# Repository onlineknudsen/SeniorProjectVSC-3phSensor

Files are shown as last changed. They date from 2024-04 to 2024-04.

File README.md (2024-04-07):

View this project on [CADLAB.io](https://cadlab.io/project/28017).

# Senior Project - Voltage Sourced Converter - 3 phase Power Sensor
### Lin Knudsen, Thomas Mack, Nikhil Patel
Chip: Atmel M90E32AS Enhanced Poly-Phase High-Performance Wide-Span
Energy Metering IC

[Datasheet](https://ww1.microchip.com/downloads/aemDocuments/documents/OTH/ProductDocuments/DataSheets/Atmel-46003-SE-M90E32AS-Datasheet.pdf)

[Application Notes](https://ww1.microchip.com/downloads/aemDocuments/documents/OTH/ApplicationNotes/ApplicationNotes/Atmel-46103-SE-M90E32AS-ApplicationNote.pdf)

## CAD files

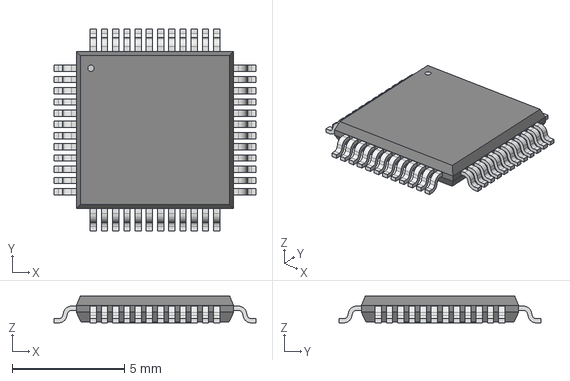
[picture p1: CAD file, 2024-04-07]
ATM90E32AS_AU_R/TQFP48_7x7MC_MCH.step
8.99 x 8.99 x 1.20 mm

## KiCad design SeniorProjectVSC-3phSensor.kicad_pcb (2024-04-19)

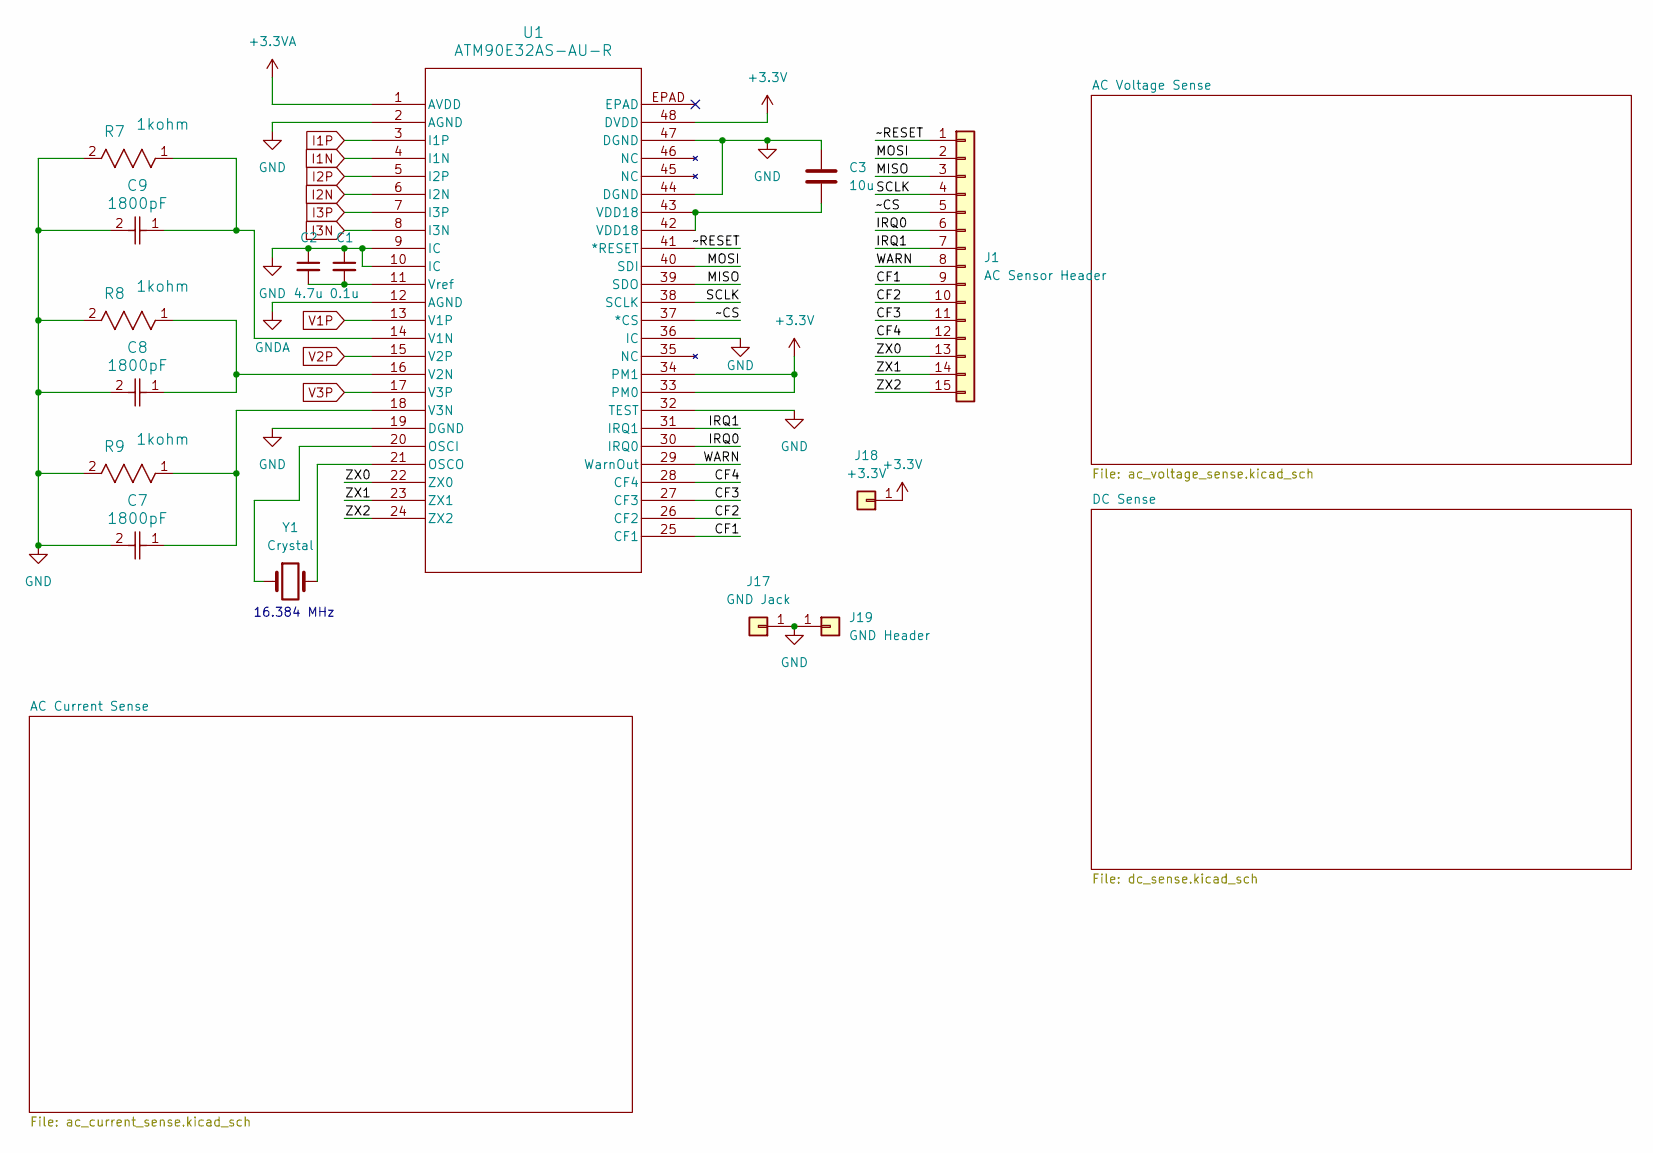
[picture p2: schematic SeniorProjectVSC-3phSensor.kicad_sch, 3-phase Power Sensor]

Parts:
C1: 0.1u; C_0805_2012Metric_Pad1.18x1.45mm_HandSolder
C2: 4.7u; C_0805_2012Metric_Pad1.18x1.45mm_HandSolder
C3: 10u; C_0805_2012Metric_Pad1.18x1.45mm_HandSolder
C7, C8, C9: 1800pF; C_0805_2012Metric_Pad1.18x1.45mm_HandSolder
J1: AC Sensor Header; PinHeader_1x15_P2.54mm_Vertical
J17: GND Jack; Banana_Jack_1Pin
J18: +3.3V; PinHeader_1x01_P2.54mm_Vertical
J19: GND Header; PinHeader_1x01_P2.54mm_Vertical
R7, R8, R9: 1kohm; R_0805_2012Metric_Pad1.20x1.40mm_HandSolder
U1: ATM90E32AS-AU-R; TQFP48_7x7MC_MCH-M
Y1: Crystal; XTAL_ABLS-16.384MHZ-B4-T

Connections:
+3.3V: J18.1, U1.33 (PM0), U1.34 (PM1), U1.48 (DVDD); also elsewhere on the board
+3.3VA: U1.1 (AVDD)
/CF1: J1.9, U1.25 (CF1)
/CF2: J1.10, U1.26 (CF2)
/CF3: J1.11, U1.27 (CF3)
/CF4: J1.12, U1.28 (CF4)
/IRQ0: J1.6, U1.30 (IRQ0)
/IRQ1: J1.7, U1.31 (IRQ1)
/MISO: J1.3, U1.39 (SDO)
/MOSI: J1.2, U1.40 (SDI)
/SCLK: J1.4, U1.38 (SCLK)
/WARN: J1.8, U1.29 (WarnOut)
/ZX0: J1.13, U1.22 (ZX0)
/ZX1: J1.14, U1.23 (ZX1)
/ZX2: J1.15, U1.24 (ZX2)
/~CS: J1.5, U1.37 (*CS)
/~RESET: J1.1, U1.41 (*RESET)
GND: C1.1, C2.1, C3.1, C7.2, C8.2, C9.2, J17.1, J19.1, R7.2, R8.2, R9.2, U1.2 (AGND), U1.9 (IC), U1.10 (IC), U1.19 (DGND), U1.32 (TEST), U1.36 (IC), U1.44 (DGND), U1.47 (DGND); also elsewhere on the board
GNDA: U1.12 (AGND)
I1N: U1.4 (I1N); also elsewhere on the board
I1P: U1.3 (I1P); also elsewhere on the board
I2N: U1.6 (I2N); also elsewhere on the board
I2P: U1.5 (I2P); also elsewhere on the board
I3N: U1.8 (I3N); also elsewhere on the board
I3P: U1.7 (I3P); also elsewhere on the board
unnamed: C3.2, U1.42 (VDD18), U1.43 (VDD18)
unnamed: U1.20 (OSCI), Y1.1
unnamed: U1.21 (OSCO), Y1.2
unnamed: C9.1, R7.1, U1.14 (V1N)
unnamed: C8.1, R8.1, U1.16 (V2N)
unnamed: C7.1, R9.1, U1.18 (V3N)
unnamed: C1.2, C2.2, U1.11 (Vref)
V1P: U1.13 (V1P); also elsewhere on the board
V2P: U1.15 (V2P); also elsewhere on the board
V3P: U1.17 (V3P); also elsewhere on the board

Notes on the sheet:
16.384 MHz

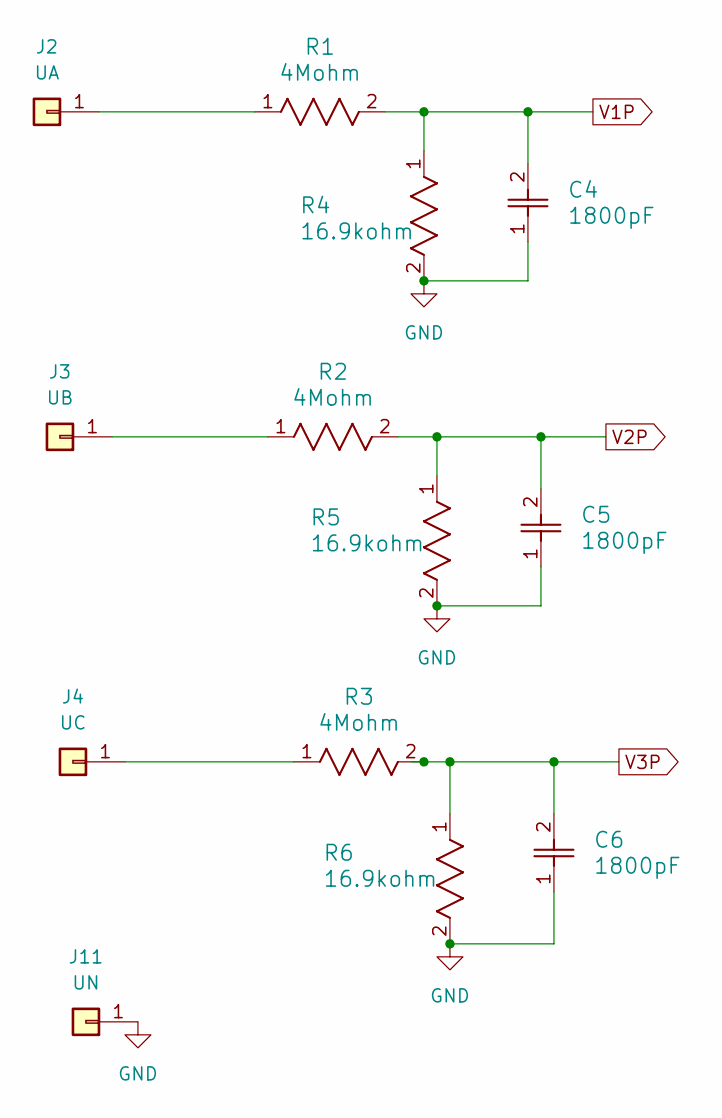
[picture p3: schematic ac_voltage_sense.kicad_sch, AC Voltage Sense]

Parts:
C4, C5, C6: 1800pF; C_0805_2012Metric_Pad1.18x1.45mm_HandSolder
J2: UA; Banana_Jack_1Pin
J3: UB; Banana_Jack_1Pin
J4: UC; Banana_Jack_1Pin
J11: UN; Banana_Jack_1Pin
R1, R2, R3: 4Mohm; R_0805_2012Metric_Pad1.20x1.40mm_HandSolder
R4, R5, R6: 16.9kohm; R_0805_2012Metric_Pad1.20x1.40mm_HandSolder

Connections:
GND: C4.1, C5.1, C6.1, J11.1, R4.2, R5.2, R6.2; also elsewhere on the board
unnamed: J2.1, R1.1
unnamed: J3.1, R2.1
unnamed: J4.1, R3.1
V1P: C4.2, R1.2, R4.1; also elsewhere on the board
V2P: C5.2, R2.2, R5.1; also elsewhere on the board
V3P: C6.2, R3.2, R6.1; also elsewhere on the board

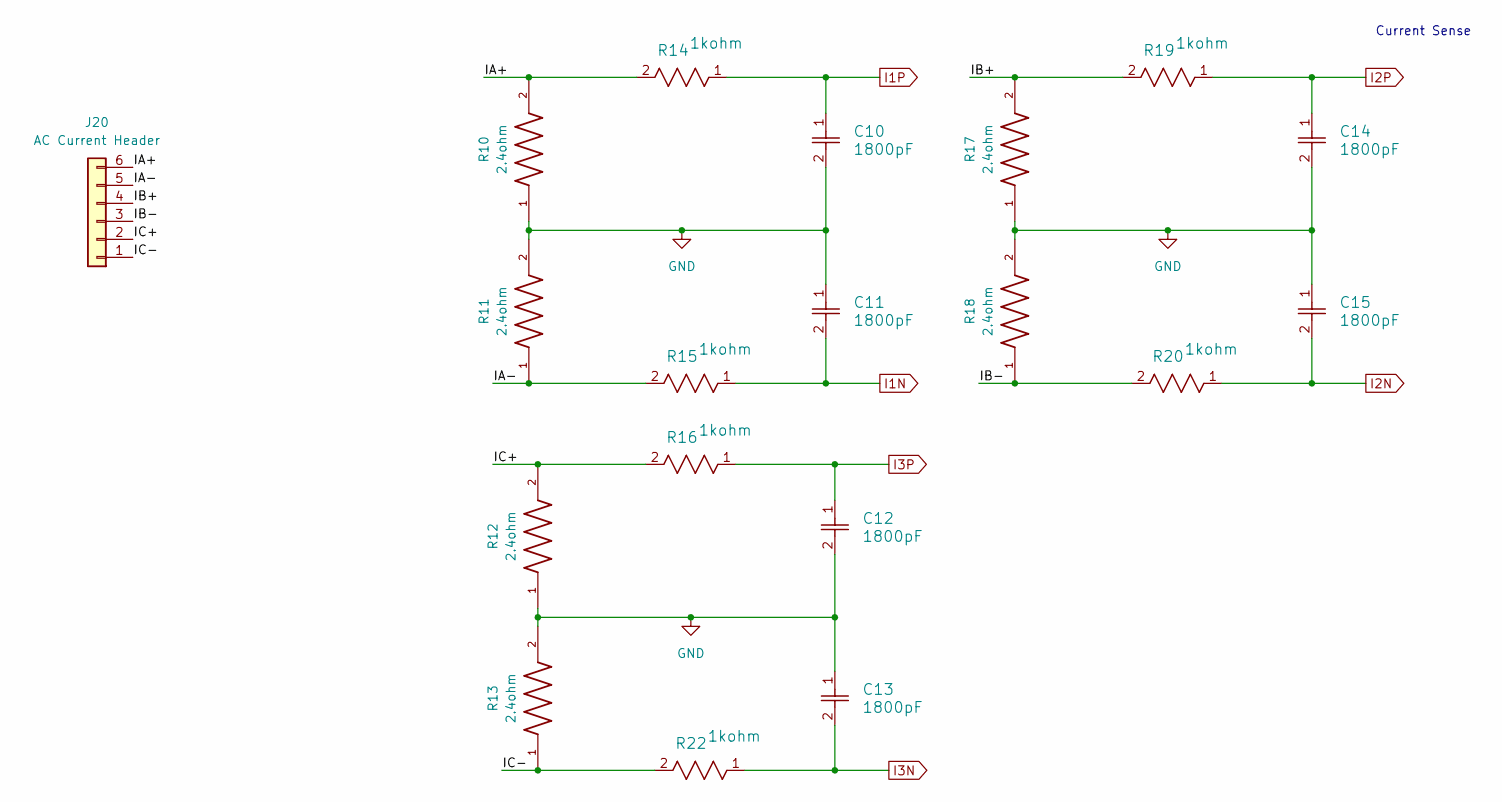
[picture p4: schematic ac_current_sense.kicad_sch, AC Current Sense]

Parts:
C10, C11, C12, C13, C14, C15: 1800pF; C_0805_2012Metric_Pad1.18x1.45mm_HandSolder
J20: AC Current Header; PinHeader_1x06_P2.54mm_Vertical
R10, R11, R12, R13, R17, R18: 2.4ohm; R_0805_2012Metric_Pad1.20x1.40mm_HandSolder
R14, R15, R16, R19, R20, R22: 1kohm; R_0805_2012Metric_Pad1.20x1.40mm_HandSolder

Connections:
/AC Current Sense/IA+: J20.6, R10.2, R14.2
/AC Current Sense/IA-: J20.5, R11.1, R15.2
/AC Current Sense/IB+: J20.4, R17.2, R19.2
/AC Current Sense/IB-: J20.3, R18.1, R20.2
/AC Current Sense/IC+: J20.2, R12.2, R16.2
/AC Current Sense/IC-: J20.1, R13.1, R22.2
GND: C10.2, C11.1, C12.2, C13.1, C14.2, C15.1, R10.1, R11.2, R12.1, R13.2, R17.1, R18.2; also elsewhere on the board
I1N: C11.2, R15.1; also elsewhere on the board
I1P: C10.1, R14.1; also elsewhere on the board
I2N: C15.2, R20.1; also elsewhere on the board
I2P: C14.1, R19.1; also elsewhere on the board
I3N: C13.2, R22.1; also elsewhere on the board
I3P: C12.1, R16.1; also elsewhere on the board

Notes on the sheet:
Current Sense

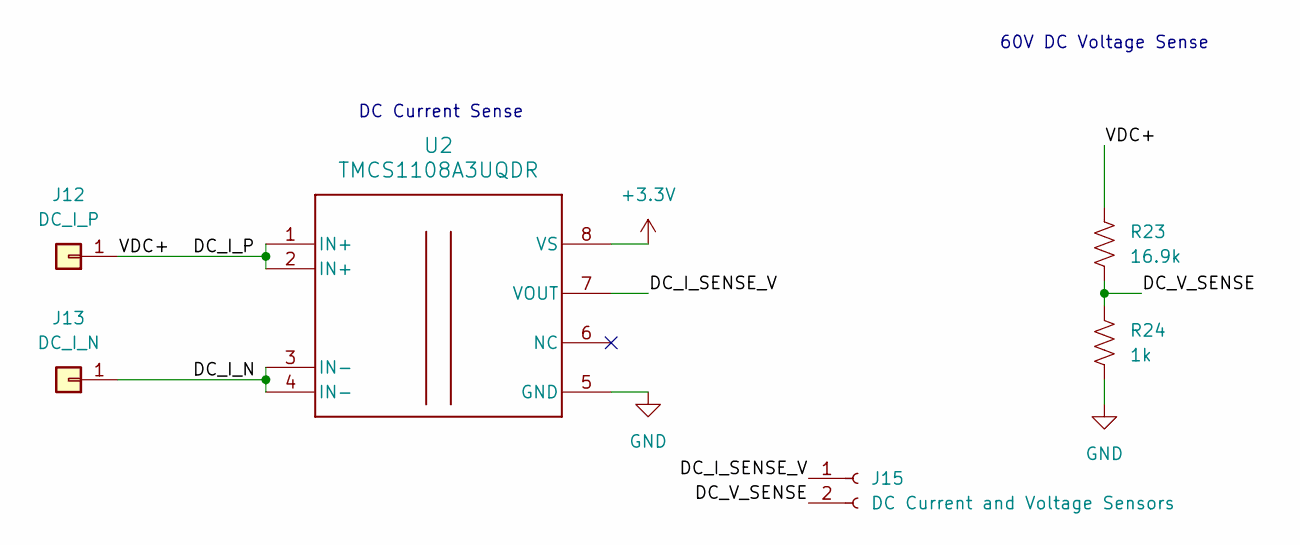
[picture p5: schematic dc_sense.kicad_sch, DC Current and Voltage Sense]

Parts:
J12: DC_I_P; Banana_Jack_1Pin
J13: DC_I_N; Banana_Jack_1Pin
J15: DC Current and Voltage Sensors; PinHeader_1x02_P2.54mm_Vertical
R23: 16.9k; R_0805_2012Metric_Pad1.20x1.40mm_HandSolder
R24: 1k; R_0805_2012Metric_Pad1.20x1.40mm_HandSolder
U2: TMCS1108A3UQDR; D0008A-IPC_A

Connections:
+3.3V: U2.8 (VS); also elsewhere on the board
/DC Sense/DC_I_N: J13.1, U2.3 (IN-), U2.4 (IN-)
/DC Sense/DC_I_P: J12.1, R23.1, U2.1 (IN+), U2.2 (IN+)
/DC Sense/DC_I_SENSE_V: J15.1, U2.7 (VOUT)
/DC Sense/DC_V_SENSE: J15.2, R23.2, R24.1
GND: R24.2, U2.5 (GND); also elsewhere on the board

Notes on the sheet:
60V DC Voltage Sense
DC Current Sense

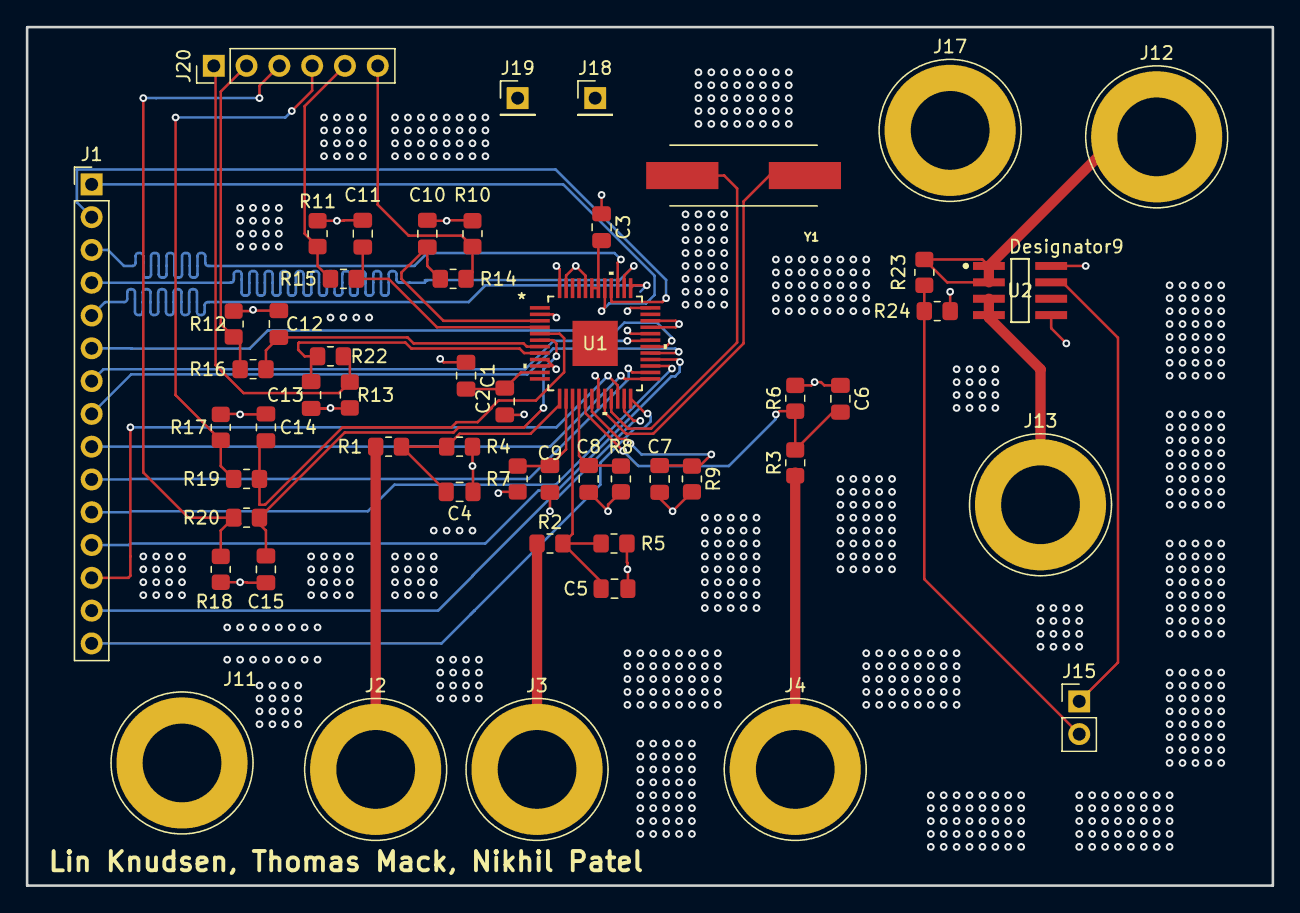
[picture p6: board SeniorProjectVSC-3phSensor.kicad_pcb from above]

Board: 4 copper layers, 96.5 x 66.5 mm, 53 parts (0 on the bottom side), 46 nets.

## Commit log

2024-04-07 Add ATM90E32AS KiCad symbol
    [SeniorProjectVSC-3phSensor.kicad_sch, TQFP48_7x7MC_MCH.step]
2024-04-08 Add M90E32AS IC and breakouts
    [SeniorProjectVSC-3phSensor.kicad_sch]
2024-04-14 Add voltage and current sensors
    [SeniorProjectVSC-3phSensor.kicad_sch]
2024-04-17 Modularize schematic and add DC voltage and current sense
    [SeniorProjectVSC-3phSensor.kicad_sch, ac_current_sense.kicad_sch, ac_voltage_sense.kicad_sch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]
2024-04-19 PCB V1
    [SeniorProjectVSC-3phSensor.kicad_pcb, SeniorProjectVSC-3phSensor.kicad_sch, ac_current_sense.kicad_sch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]
